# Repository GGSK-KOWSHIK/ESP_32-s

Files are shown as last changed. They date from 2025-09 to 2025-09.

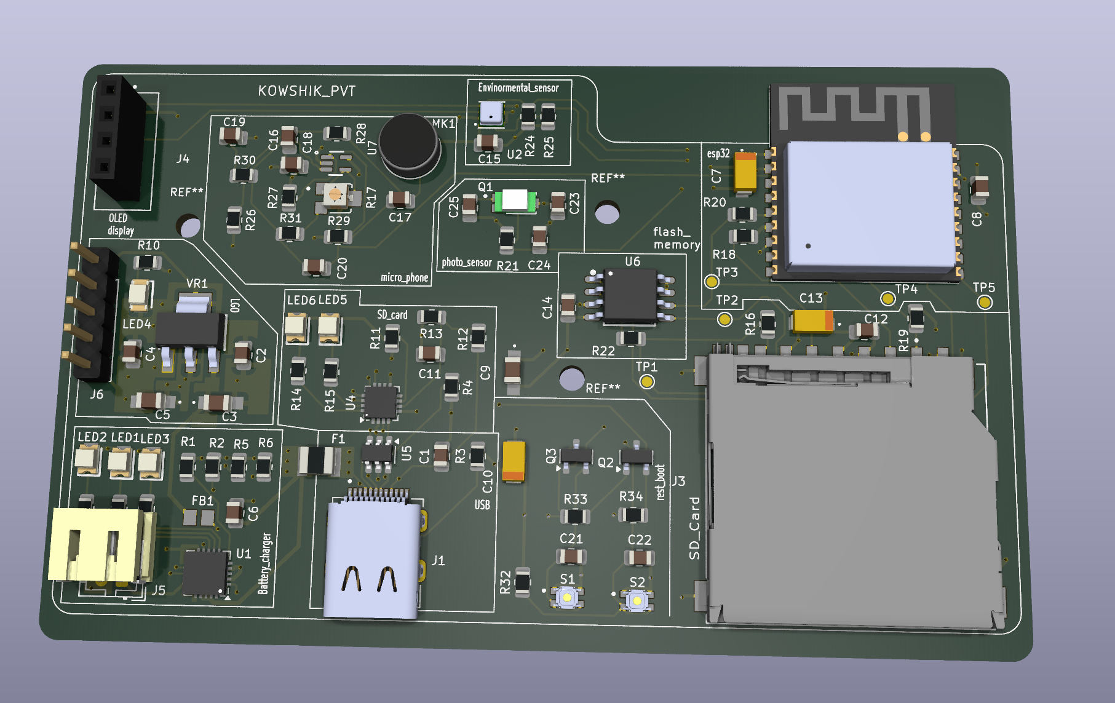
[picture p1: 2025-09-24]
Images/PCB_3D.png

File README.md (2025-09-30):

## Project Summary:4 Layers Custom IoT PCB with ESP32-C3-02.

This project involves the design and development of a **4-layer custom PCB** for an IoT application powered by the ESP32-C3-02 SoC. The board integrates **Wi-Fi/BLE connectivity** and **TP4056-based Li-ion charging circuitry**, enabling efficient and safe charging of a single-cell Li-ion battery.

### Key Features

- **Microcontroller**: ESP32-C3-02 SoC with Wi-Fi and BLE connectivity  
- **Power Management**: TP4056 IC for single-cell Li-ion battery charging with thermal regulation  
- **Battery Protection**: Integrated under-voltage lockout and trickle charging  
- **Sensors and Modules**:  
  - BME280 for temperature, humidity, and pressure sensing  
  - Ambient light and sound sensors  
  - Mini SD card reader for local data storage  
  - Onboard flash memory for extended storage  
- **Display**: I2C OLED for real-time data visualization  
- **Power Inputs**:  
  - USB-C connector for charging and data transfer  
  - LiPo battery connector with onboard charging circuitry  
- **Indicators**: LED indicators showing charging and full-charge status  

### Design Highlights

1. **Power Supply Integration**  
   - USB-C powers both charging and system operation  
   - TP4056 manages charging and protection  
   - Regulated supply ensures ESP32-C3-02 stability  

2. **Modular Architecture**  
   - Supports multiple onboard sensors  
   - Expandable via additional I2C devices  

3. **Safe and Efficient Charging**  
   - Programmable charging current (external resistor)  
   - Automatic charge termination and built-in protection  

4. **Compact and Reliable Layout**  
   - Optimized **4-layer PCB routing** for minimal power loss  
   - Thermal management for TP4056 and critical components  

### Applications

- IoT edge devices for environmental monitoring  
- Low-power battery-operated data logging systems  
- Prototyping platform for ESP32-based IoT solutions

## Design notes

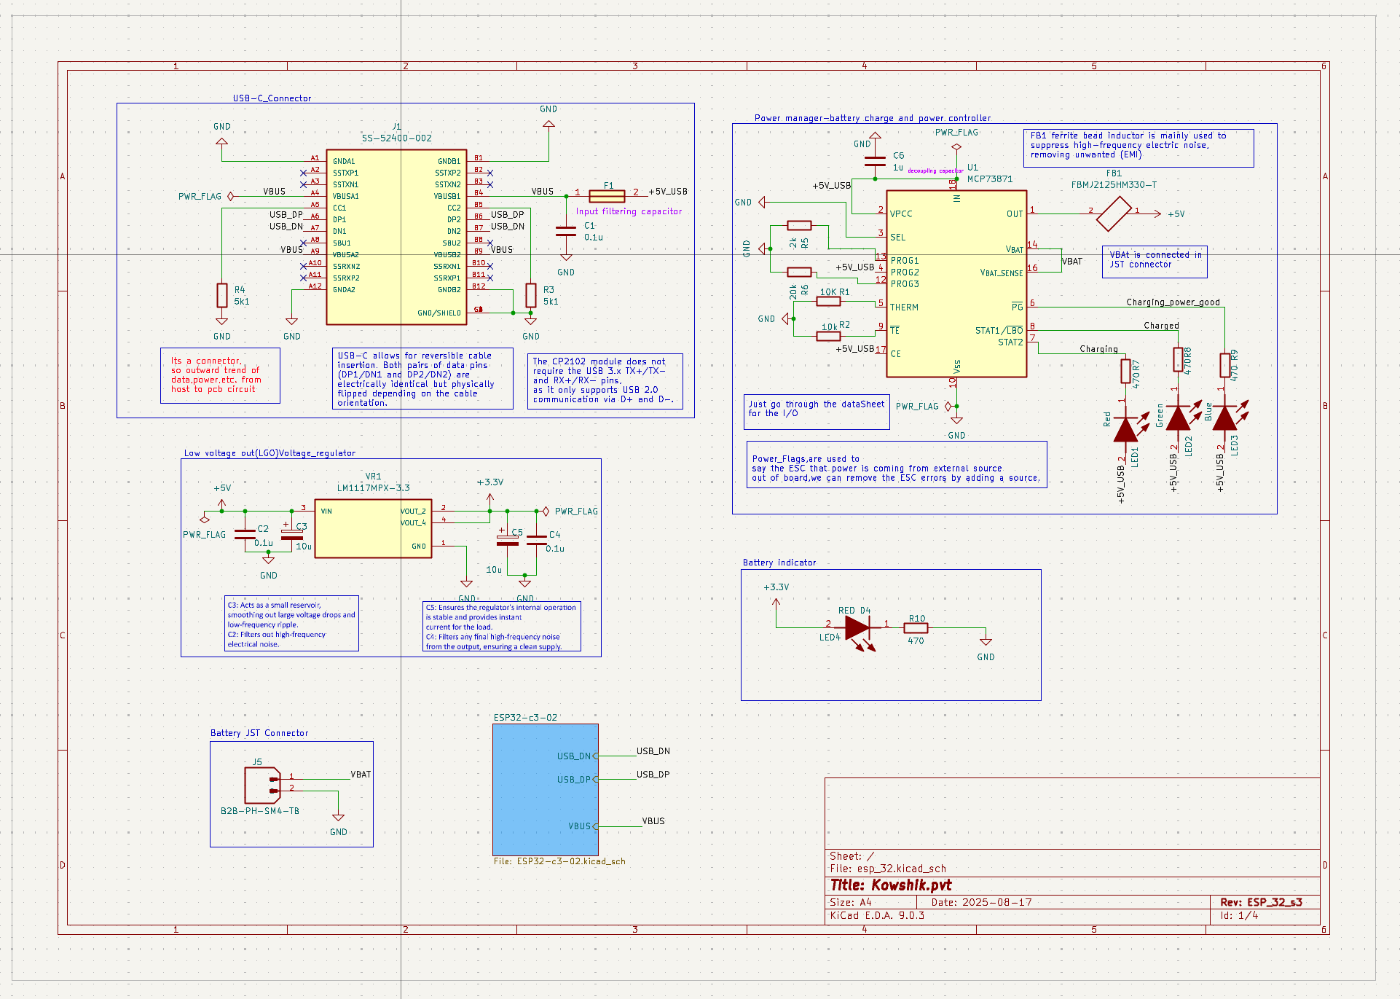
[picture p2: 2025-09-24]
Images/Schematic_1.png

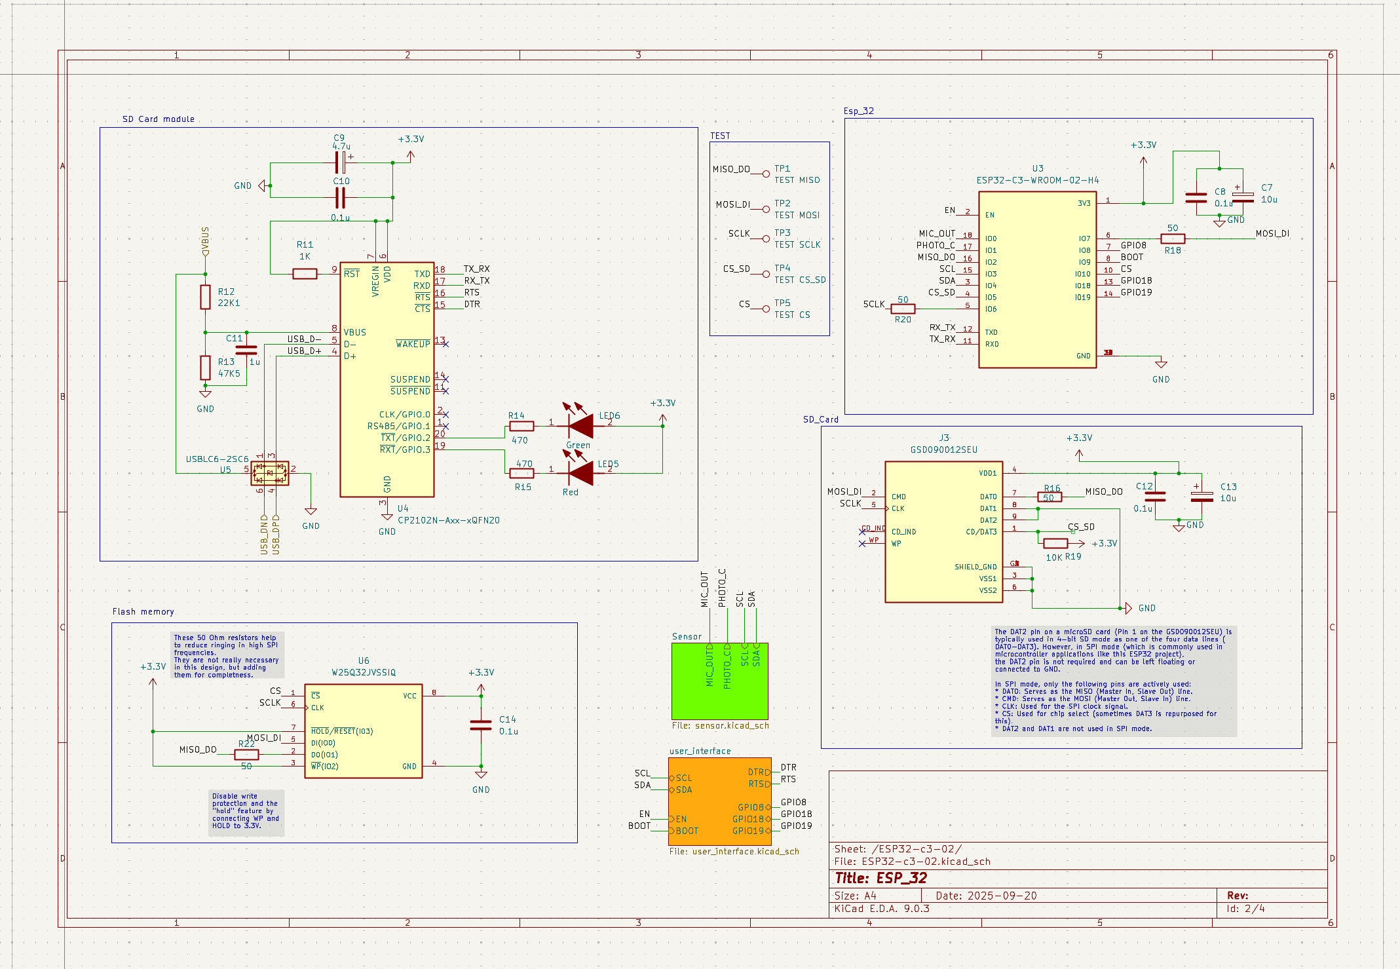
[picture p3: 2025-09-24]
Images/schematic_2.png

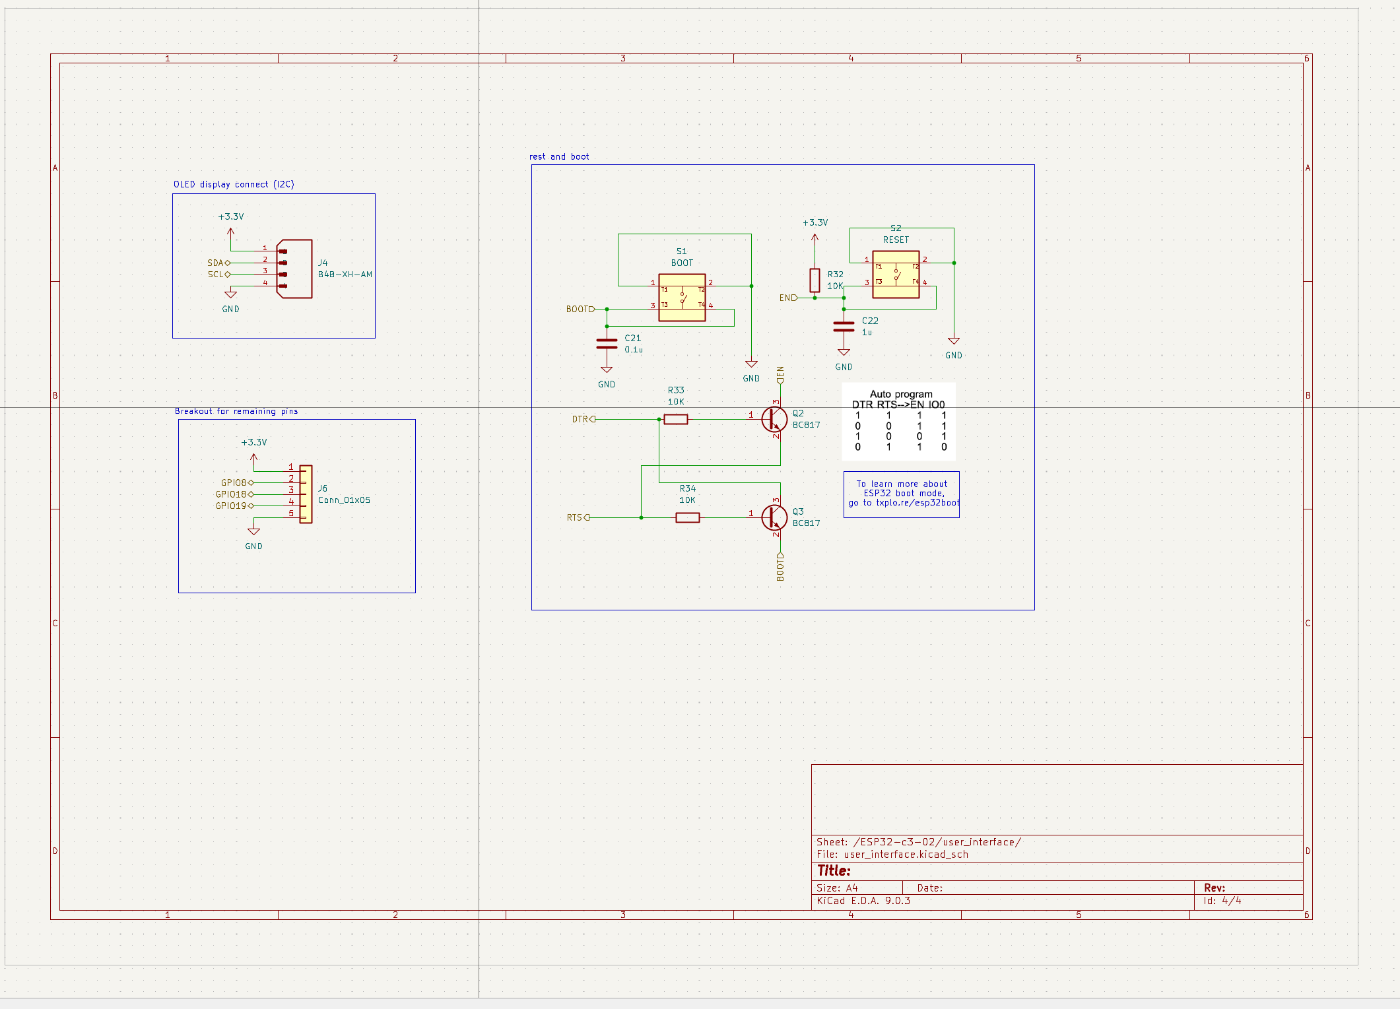
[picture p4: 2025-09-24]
Images/schematic_3.png

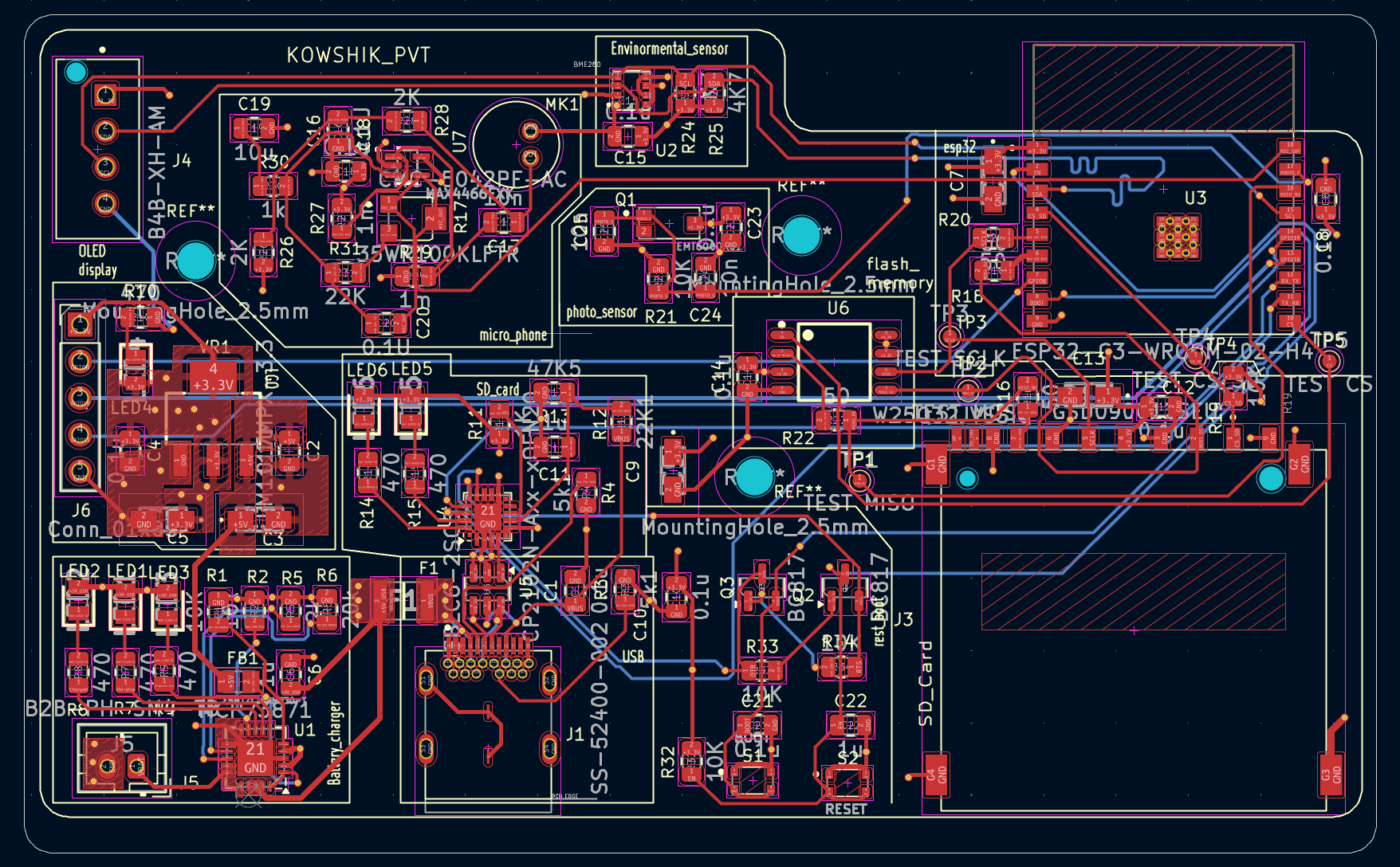
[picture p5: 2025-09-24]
Images/PCB.png

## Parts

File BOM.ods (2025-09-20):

DESIGNATOR | QTY | VALUE | MANUF. PART No | MANUFACTURER | PACKAGE | DESCRIPTION
C1, C2, C5, C8, C10, C13-C16, C18, C21, C23 | 12 | 0.1u | C0805C104K4RAC | KEMET | 0805 | Multilayer Ceramic Capacitors MLCC - SMD/SMT 16V 0.1uF X7R 0805 10%
C3, C4, C7, C12 | 4 | 10u | T491A106K010AT7280 | KEMET | 1206 | T491, Tantalum, MnO2 Tantalum, Commercial Grade, 10 uF, 10%, 10 VDC, 125C, -55C, 85C, SMD, MnO2, Molded, 6 % , 3.8 Ohms, 1000 nA, 58.6 mg, 3216, 1.6mm, Height Max = 1.8mm, 9000, 156 Weeks
C6, C11, C22 | 3 | 1u | C0805C105K4RACTU | KEMET | 0805 | Multilayer Ceramic Capacitors MLCC - SMD/SMT 16V 1uF X7R 0805 10%
C9 | 1 | 4.7u | T491A475K010AT7280 | KEMET | 1206 | T491, Tantalum, MnO2 Tantalum, Commercial Grade, 4.7 uF, 10%, 10 VDC, 125C, -55C, 85C, SMD, MnO2, Molded, 6 % , 4 Ohms, 500 nA, 58.6 mg, 3216, 1.6mm, Height Max = 1.8mm, 9000, 156 Weeks
C17, C24, C25 | 3 | 10n | C0603C103K4RACTU | KEMET | 0603 | Multilayer Ceramic Capacitors MLCC - SMD/SMT 16V 0.01uF X7R 0603 10%
C19 | 1 | 10uF | C1206C106K4RAC | KEMET | 1206 | Multilayer Ceramic Capacitors MLCC - SMD/SMT 16V 10uF X7R 1206 10%
C20 | 1 | 100pF | C0603C101K4RACTU | KEMET | 0603 | Multilayer Ceramic Capacitors MLCC - SMD/SMT 16V 100pF X7R 0603 10%
D1, D4, D6 | 3 | RED | LTST-C170KRKT | Lite-On | 0805 | Standard LEDs - SMD Red Clear 631nm
D2, D5 | 2 | GREEN | LTST-C170GKT | Lite-On | 0805 | LED,SMD,0805,Green,6mcd,130deg Lite-On LTST-C170GKT, CHIPLED 0805 Series Green LED, 569 nm 2012 (0805), Rectangle Lens SMD package
D3 | 1 | BLUE | LTST-C170TBKT | Lite-On | 0805 | LED,SMD,0805,Blue,28mcd,130deg
F1 | 1 | 0ZCH0110AF2E | 0ZCH0110AF2E | Belfuse | 1210 | 1210 SMT PPTC | 1.10 Ih | 16V
J1 | 1 | USB_C_Receptacle | SS-52400-002 | STEWART CONNECTOR | USB Type-C | USB 2.0-only Type-C Receptacle connector
J2 | 1 | JST_2mm_LiPo | PHR-2 | JST |  | 2 Pin 2mm JST Battery Connector
J3 | 1 | GSD090012SEU | GSD090012SEU | Amphenol |  | Memory Card Connectors SD CARD CONNECTOR 9 POS, SMT
J4, J5 | 2 | B4B-XH-AM | B4B-XH-AM | JST |  | Connector header vertical 4pos 2.5mm
J6 | 1 | Conn_01x05 |  |  |  | Header 1X5, 2.54mm
L1 | 1 |  | FBMJ2125HM330 | TAIYO YUDEN | 0805 | Ferrite Bead 0805 4A 33OHMS 25%
MK1 | 1 | CMC-5042PF-AC | CMC-5042PF-AC | CUI INC
Q1 | 1 | TEMT6000X01 | TEMT6000X01 | VISHAY | 4 mm x 2 mm x 1.05 mm | Ambient Light Sensors Ambient Light Sensor AEC-Q101 Qualified
Q2, Q3 | 2 | BC817 | BC817 |  | SOT-23 | 0.8A Ic, 45V Vce, NPN Transistor, SOT-23
R1, R2, R19, R23, R32-R34 | 7 | 10K |  |  | 805 | SMD resistor, 0805, 125mW, 1%
R3, R4 | 2 | 5k1 |  |  | 0805 | SMD resistor, 0805, 125mW, 1%
R5, R26, R28 | 3 | 2K |  |  | 0805 | SMD resistor, 0805, 125mW, 1%
R6 | 1 | 20K |  |  | 0805 | SMD resistor, 0805, 125mW, 1%
R7-R9 | 3 | 470 |  |  | 0805 | SMD resistor, 0805, 125mW, 1%
R10, R14, R18 | 3 | 330 |  |  | 0805 | SMD resistor, 0805, 125mW, 1%
R11, R30 | 2 | 1K |  |  | 0805 | SMD resistor, 0805, 125mW, 1%
R12 | 1 | 22K1 |  |  | 0805 | SMD resistor, 0805, 125mW, 1%
R13 | 1 | 47K5 |  |  | 0805 | SMD resistor, 0805, 125mW, 1%
R15-R17, R20-R22 | 6 | 50 |  |  | 0805 | SMD resistor, 0805, 125mW, 1%
R24, R25 | 2 | 4K7 |  |  | 0805 | SMD resistor, 0805, 125mW, 1%
R27, R29 | 2 | 1M |  |  | 0805 | SMD resistor, 0805, 125mW, 1%
R31 | 1 | 22K |  |  | 0805 | SMD resistor, 0805, 125mW, 1%
SW1, SW2 | 2 | TL3305AF260QG | TL3305AF260QG | E-Switch |  | Tactile Switches 50mA 12VDC SPST, NO 3.8mm Act 260gf
U1 | 1 | MCP73871 | MCP73871-4CCI/ML | Microchip | QFN-20 | Single cell, Li-Ion/Li-Po charge management controller
U2 | 1 | LM1117MPX-3.3_NOPB | LM1117MPX-3.3/NOPB | Texas Instruments | SOT-223-4 | Space saving 800-mA low-dropout linear regulator with internal current limit
U3 | 1 | ESP32-C3-WROOM-02-H4 | ESP32-C3-WROOM-02-H4 | Espressif |  | Multiprotocol Modules SMD module, ESP32-C3, 4MB SPI flash, PCB antenna
U4 | 1 | CP2102N-A02-GQFN20 | CP2102N-A02-GQFN20 | Silicon Laboratories | QFN20 | USB to UART Bridge
U5 | 1 | USBLC6-2SC6 | USBLC6-2SC6 | STMicroelectronics | SOT-23-6 | ESD Suppressors / TVS Diodes ESD Protection Low Cap
U6 | 1 | W25Q32JVSSIQ | W25Q32JVSSIQ | Winbond | SOIC-8 | NOR Flash spiFlash, 32M-bit, 4Kb Uniform Sector
U7 | 1 | BME280 | BME280 | Bosch | LGA-8 | Air Quality Sensor MEMS humidity, pressure and temperature sensor
U8 | 1 | MAX4466EXK+T | MAX4466EXK+T | Analog Devices Inc. | SC-70-5 | Microphone Preamplifier
VR1 | 1 | 35WR100KLFTR | 35WR100KLFTR | TT Electronics |  | Trimmer Resistor - SMD 3mm 100K Open Type

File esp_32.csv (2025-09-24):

Reference | Qty | Value | DNP | Exclude from BOM | Exclude from Board | Footprint | Datasheet
C1,C2,C4,C8,C10,C12,C14,C15,C18,C21,C23 | 11 | 0.1u |  |  |  | Capacitor_SMD:C_0805_2012Metric | ~
C3,C5,C7,C13 | 4 | 10u |  |  |  | Footprints:T491A | ~
C6,C11,C22 | 3 | 1u |  |  |  | Capacitor_SMD:C_0805_2012Metric | ~
C9 | 1 | 4.7u |  |  |  | Footprints:T491A | ~
C16,C20 | 2 | 0.1U |  |  |  | Capacitor_SMD:C_0805_2012Metric | ~
C17,C24,C25 | 3 | 10n |  |  |  | Capacitor_SMD:C_0805_2012Metric | ~
C19 | 1 | 10u |  |  |  | Capacitor_SMD:C_0805_2012Metric | ~
F1 | 1 | 0ZCH0110AF2E |  |  |  | Footprints:FUSC3226X100N | https://www.belfuse.com/resources/datasheets/circuitprotection/ds-cp-0zch-series.pdf
FB1 | 1 | FBMJ2125HM330-T |  |  |  | Footprints:BEADC2012X105N
J1 | 1 | SS-52400-002 |  |  |  | Footprints:BELFUSE_SS-52400-002
J3 | 1 | GSD090012SEU |  |  |  | Footprints:AMPHENOL_GSD090012SEU
J4 | 1 | B4B-XH-AM |  |  |  | Footprints:JST_B4B-XH-AM__LF__SN_
J5 | 1 | B2B-PH-SM4-TB |  |  |  | Connector_JST:JST_PH_B2B-PH-K_1x02_P2.00mm_Vertical
J6 | 1 | Conn_01x05 |  |  |  | Connector_PinHeader_2.54mm:PinHeader_1x05_P2.54mm_Vertical | ~
LED1,LED5 | 2 | Red |  |  |  | Footprints:LEDC2012X120N | https://componentsearchengine.com/Datasheets/1/LTST-C170KRKT.pdf
LED2,LED6 | 2 | Green |  |  |  | Footprints:LEDC2012X120N | https://mm.digikey.com/Volume0/opasdata/d220001/medias/docus/895/LTST-C170GKT.pdf
LED3 | 1 | Blue |  |  |  | Footprints:LEDC2012X120N | https://componentsearchengine.com/Datasheets/1/LTST-C170TBKT.pdf
LED4 | 1 | RED D4 |  |  |  | Footprints:LEDC2012X120N | https://componentsearchengine.com/Datasheets/1/LTST-C170KRKT.pdf
MK1 | 1 | CMC-5042PF-AC |  |  |  | Footprints:CUI_CMC-5042PF-AC
Q1 | 1 | TEMT6000X01 |  |  |  | Footprints:TRANS_TEMT6000X01
Q2,Q3 | 2 | BC817 |  |  |  | Package_TO_SOT_SMD:SOT-23 | https://www.onsemi.com/pub/Collateral/BC818-D.pdf
R1,R19,R21,R32,R33,R34 | 6 | 10K |  |  |  | Resistor_SMD:R_0805_2012Metric | ~
R2 | 1 | 10k |  |  |  | Resistor_SMD:R_0805_2012Metric | ~
R3,R4 | 2 | 5k1 |  |  |  | Resistor_SMD:R_0805_2012Metric | ~
R5 | 1 | 2k |  |  |  | Resistor_SMD:R_0805_2012Metric | ~
R6 | 1 | 20k |  |  |  | Resistor_SMD:R_0805_2012Metric | ~
R7,R8,R9,R10,R14,R15 | 6 | 470 |  |  |  | Resistor_SMD:R_0805_2012Metric | ~
R11 | 1 | 1K |  |  |  | Resistor_SMD:R_0805_2012Metric | ~
R12 | 1 | 22K1 |  |  |  | Resistor_SMD:R_0805_2012Metric | ~
R13 | 1 | 47K5 |  |  |  | Resistor_SMD:R_0805_2012Metric | ~
R16,R18,R20,R22 | 4 | 50 |  |  |  | Resistor_SMD:R_0805_2012Metric | ~
R17 | 1 | 35WR100KLFTR |  |  |  | Footprints:TRIM_35WR100KLFTR
R24,R25 | 2 | 4K7 |  |  |  | Resistor_SMD:R_0805_2012Metric | ~
R26,R28 | 2 | 2K |  |  |  | Resistor_SMD:R_0805_2012Metric | ~
R27,R29 | 2 | 1m |  |  |  | Resistor_SMD:R_0805_2012Metric | ~
R30 | 1 | 1k |  |  |  | Resistor_SMD:R_0805_2012Metric | ~
R31 | 1 | 22K |  |  |  | Resistor_SMD:R_0805_2012Metric | ~
S1 | 1 | BOOT |  |  |  | Footprints:SW_USLPT2819DT2TR
S2 | 1 | RESET |  |  |  | Footprints:SW_USLPT2819DT2TR
TP1 | 1 | TEST MISO |  |  |  | TestPoint:TestPoint_Pad_D1.0mm | ~
TP2 | 1 | TEST MOSI |  |  |  | TestPoint:TestPoint_Pad_D1.0mm | ~
TP3 | 1 | TEST SCLK |  |  |  | TestPoint:TestPoint_Pad_D1.0mm | ~
TP4 | 1 | TEST CS_SD |  |  |  | TestPoint:TestPoint_Pad_D1.0mm | ~
TP5 | 1 | TEST CS |  |  |  | TestPoint:TestPoint_Pad_D1.0mm | ~
U1 | 1 | MCP73871 |  |  |  | Package_DFN_QFN:QFN-20-1EP_4x4mm_P0.5mm_EP2.5x2.5mm | http://www.mouser.com/ds/2/268/22090a-52174.pdf
U2 | 1 | BME280 |  |  |  | Footprints:PSON65P250X250X100-8N
U3 | 1 | ESP32-C3-WROOM-02-H4 |  |  |  | Footprints:MODULE_ESP32-C3-WROOM-02-H4
U4 | 1 | CP2102N-Axx-xQFN20 |  |  |  | Package_DFN_QFN:SiliconLabs_QFN-20-1EP_3x3mm_P0.5mm_EP1.8x1.8mm | https://www.silabs.com/documents/public/data-sheets/cp2102n-datasheet.pdf
U5 | 1 | USBLC6-2SC6 |  |  |  | Package_TO_SOT_SMD:SOT-23-6 | https://www.st.com/resource/en/datasheet/usblc6-2.pdf
U6 | 1 | W25Q32JVSSIQ |  |  |  | Footprints:SOIC127P790X216-8N
U7 | 1 | MAX4466EXK |  |  |  | Footprints:SOT65P210X110-5N
VR1 | 1 | LM1117MPX-3.3 |  |  |  | Footprints:VREG_LM1117MPX-3.3

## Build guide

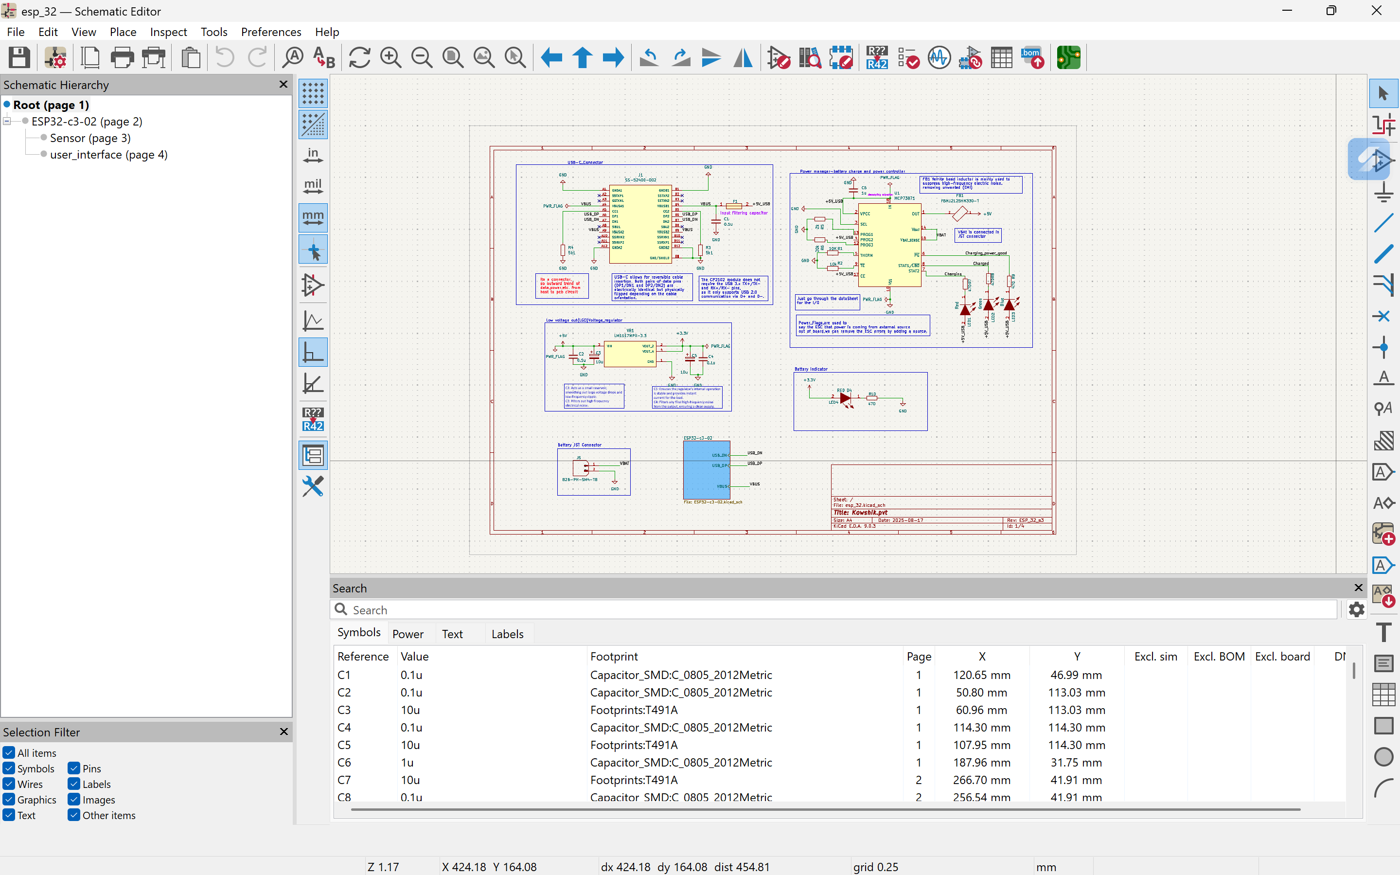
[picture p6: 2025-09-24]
Images/complete_setup.png

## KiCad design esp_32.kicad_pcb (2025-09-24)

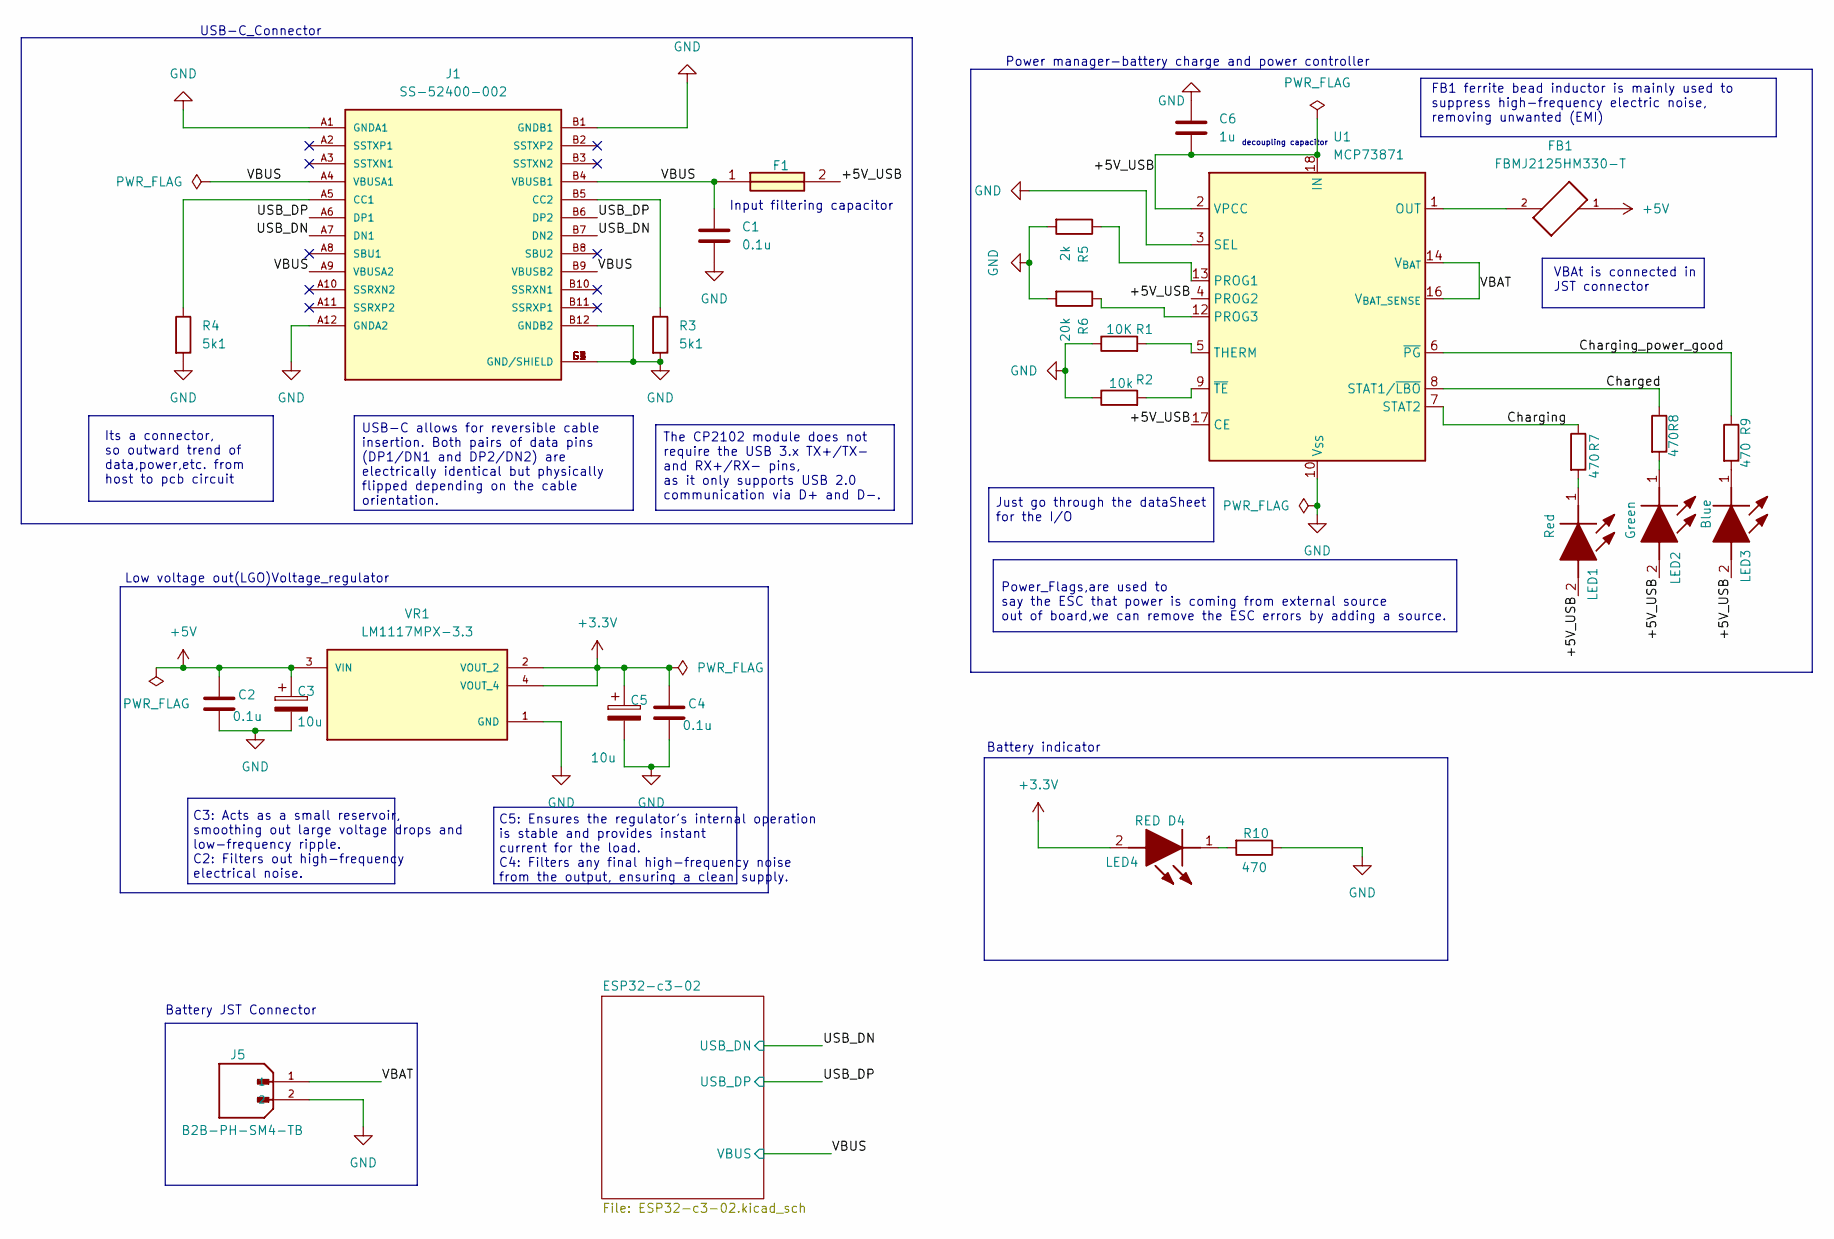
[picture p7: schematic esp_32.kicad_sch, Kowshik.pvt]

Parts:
C1, C2, C4: 0.1u; C_0805_2012Metric
C3, C5: 10u; T491A
C6: 1u; C_0805_2012Metric
F1: 0ZCH0110AF2E; FUSC3226X100N; Manufacturer_Part_Number 0ZCH0110AF2E
FB1: FBMJ2125HM330-T; BEADC2012X105N
J1: SS-52400-002; BELFUSE_SS-52400-002; PARTREV A0
J5: B2B-PH-SM4-TB; JST_PH_B2B-PH-K_1x02_P2.00mm_Vertical; PARTREV N/A
LED1: Red; LEDC2012X120N; Manufacturer_Part_Number LTST-C170KRKT; Mouser Part Number 859-LTST-C170KRKT
LED2: Green; LEDC2012X120N; Manufacturer_Part_Number LTST-C170GKT; Mouser Part Number 859-LTST-C170GKT
LED3: Blue; LEDC2012X120N; Manufacturer_Part_Number LTST-C170TBKT; Mouser Part Number 859-LTST-C170TBKT
LED4: RED D4; LEDC2012X120N; Manufacturer_Part_Number LTST-C170KRKT; Mouser Part Number 859-LTST-C170KRKT
R1: 10K; R_0805_2012Metric
R2: 10k; R_0805_2012Metric
R3, R4: 5k1; R_0805_2012Metric
R5: 2k; R_0805_2012Metric
R6: 20k; R_0805_2012Metric
R7, R8, R9, R10: 470; R_0805_2012Metric
U1: MCP73871; QFN-20-1EP_4x4mm_P0.5mm_EP2.5x2.5mm
VR1: LM1117MPX-3.3; VREG_LM1117MPX-3.3

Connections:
+3.3V: C4.1, C5.1, LED4.2 (A), VR1.2 (VOUT_2), VR1.4 (VOUT_4); also elsewhere on the board
+5V: C2.1, C3.1, FB1.1, VR1.3 (VIN)
/+5V_USB: C6.2, F1.2, LED1.2 (A), LED2.2 (A), LED3.2 (A), U1.2 (VPCC), U1.4 (PROG2), U1.17 (CE), U1.18 (IN), U1.19 (IN)
/Charged: R8.1, U1.8 (STAT1/~LBO)
/Charging: R7.1, U1.7 (STAT2)
/Charging_power_good: R9.1, U1.6 (~PG)
/USB_DN: J1.A7 (DN1), J1.B7 (DN2); also elsewhere on the board
/USB_DP: J1.A6 (DP1), J1.B6 (DP2); also elsewhere on the board
/VBAT: J5.1, U1.14 (V_{BAT}), U1.15 (V_{BAT}), U1.16 (V_{BAT_SENSE})
/VBUS: C1.1, F1.1, J1.A4 (VBUSA1), J1.A9 (VBUSA2), J1.B4 (VBUSB1), J1.B9 (VBUSB2); also elsewhere on the board
GND: C1.2, C2.2, C3.2, C4.2, C5.2, C6.1, J1.A1 (GNDA1), J1.A12 (GNDA2), J1.B1 (GNDB1), J1.B12 (GNDB2), J1.G1 (GND/SHIELD), J1.G2 (GND/SHIELD), J1.G3 (GND/SHIELD), J1.G4 (GND/SHIELD), J1.S1 (GND/SHIELD), J1.S2 (GND/SHIELD), J1.S3 (GND/SHIELD), J1.S4 (GND/SHIELD), J5.2, R1.1, R2.1, R3.2, R4.2, R5.2, R6.2, R10.1, U1.3 (SEL), U1.10 (V_{SS}), U1.11 (V_{SS}), U1.21 (V_{SS}), VR1.1 (GND); also elsewhere on the board
unnamed: FB1.2, U1.1 (OUT), U1.20 (OUT)
unnamed: J1.A5 (CC1), R4.1
unnamed: J1.B5 (CC2), R3.1
unnamed: LED1.1 (K), R7.2
unnamed: LED2.1 (K), R8.2
unnamed: LED3.1 (K), R9.2
unnamed: LED4.1 (K), R10.2
unnamed: R5.1, U1.13 (PROG1)
unnamed: R6.1, U1.12 (PROG3)
unnamed: R1.2, U1.5 (THERM)
unnamed: R2.2, U1.9 (~TE)

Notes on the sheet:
Input filtering capacitor
Power manager-battery charge and power controller
C3: Acts as a small reservoir, smoothing out large voltage drops and low-frequency ripple. C2: Filters out high-frequency electrical noise.
Battery indicator
Low voltage out(LGO)Voltage_regulator
Battery JST Connector
Power_Flags,are used to say the ESC that power is coming from external source out of board,we can remove the ESC errors by adding a source.
VBAt is connected in JST connector
Its a connector, so outward trend of data,power,etc. from host to pcb circuit
C5: Ensures the regulator's internal operation is stable and provides instant current for the load. C4: Filters any final high-frequency noise from the output, ensuring a clean supply.
decoupling capacitor
USB-C_Connector
Just go through the dataSheet for the I/O
FB1 ferrite bead inductor is mainly used to suppress high-frequency electric noise, removing unwanted (EMI)
USB-C allows for reversible cable insertion. Both pairs of data pins (DP1/DN1 and DP2/DN2) are electrically identical but physically flipped depending on the cable orientation.
The CP2102 module does not require the USB 3.x TX+/TX- and RX+/RX- pins, as it only supports USB 2.0 communication via D+ and D-.

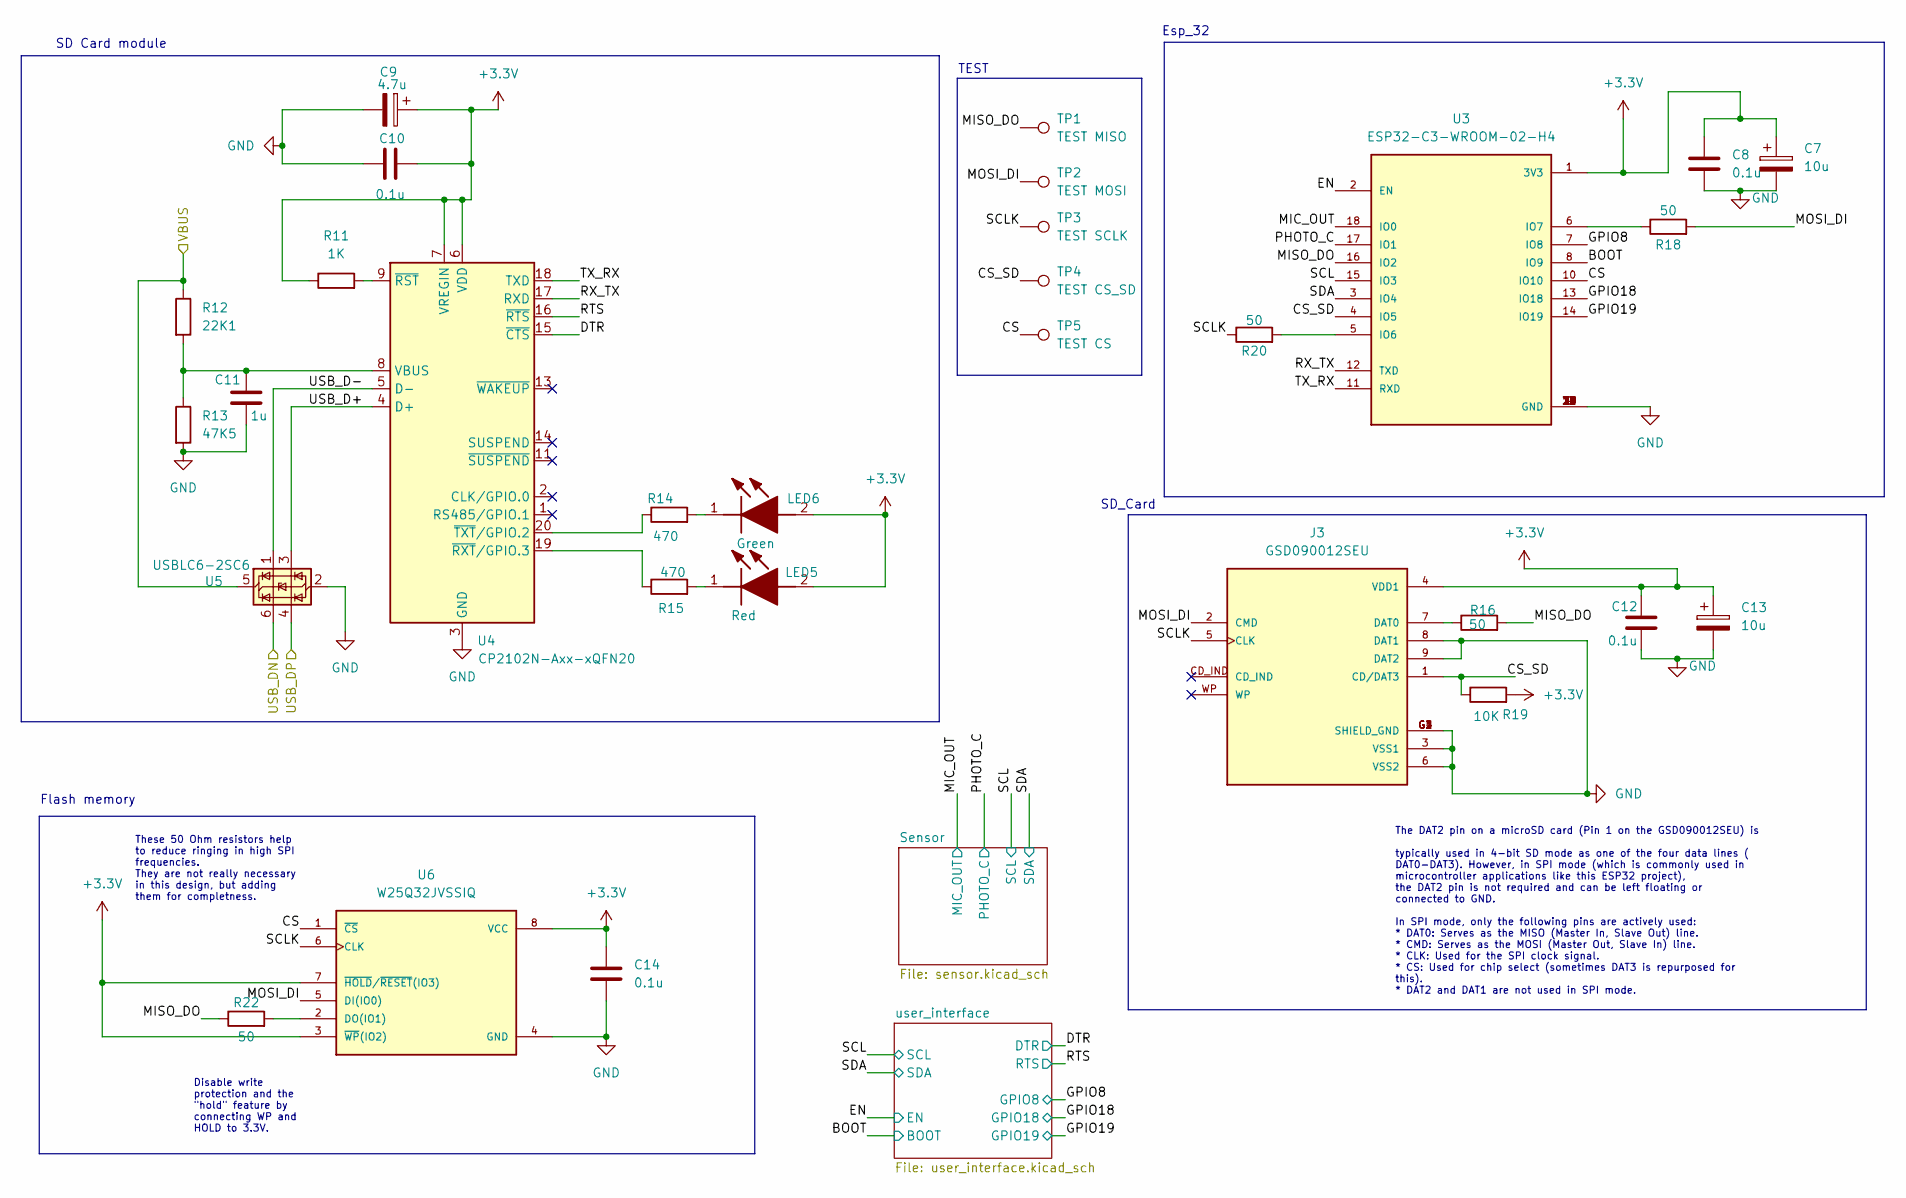
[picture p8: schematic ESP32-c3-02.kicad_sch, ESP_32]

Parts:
C7, C13: 10u; T491A
C8, C10, C12, C14: 0.1u; C_0805_2012Metric
C9: 4.7u; T491A
C11: 1u; C_0805_2012Metric
J3: GSD090012SEU; AMPHENOL_GSD090012SEU; PARTREV E
LED5: Red; LEDC2012X120N; Manufacturer_Part_Number LTST-C170KRKT; Mouser Part Number 859-LTST-C170KRKT
LED6: Green; LEDC2012X120N; Manufacturer_Part_Number LTST-C170GKT; Mouser Part Number 859-LTST-C170GKT
R11: 1K; R_0805_2012Metric
R12: 22K1; R_0805_2012Metric
R13: 47K5; R_0805_2012Metric
R14, R15: 470; R_0805_2012Metric
R16, R18, R20, R22: 50; R_0805_2012Metric
R19: 10K; R_0805_2012Metric
TP1: TEST MISO; TestPoint_Pad_D1.0mm
TP2: TEST MOSI; TestPoint_Pad_D1.0mm
TP3: TEST SCLK; TestPoint_Pad_D1.0mm
TP4: TEST CS_SD; TestPoint_Pad_D1.0mm
TP5: TEST CS; TestPoint_Pad_D1.0mm
U3: ESP32-C3-WROOM-02-H4; MODULE_ESP32-C3-WROOM-02-H4
U4: CP2102N-Axx-xQFN20; SiliconLabs_QFN-20-1EP_3x3mm_P0.5mm_EP1.8x1.8mm
U5: USBLC6-2SC6; SOT-23-6
U6: W25Q32JVSSIQ; SOIC127P790X216-8N; M_PART_NUMBER W25QXX

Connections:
+3.3V: C7.1, C8.1, C9.1, C10.2, C12.1, C13.1, C14.1, J3.4 (VDD1), LED5.2 (A), LED6.2 (A), R11.1, R19.2, U3.1 (3V3), U4.6 (VDD), U4.7 (VREGIN), U6.3 (~WP(IO2)), U6.7 (~HOLD/~RESET(IO3)), U6.8 (VCC); also elsewhere on the board
/ESP32-c3-02/BOOT: U3.8 (IO9); also elsewhere on the board
/ESP32-c3-02/CS: TP5.1, U3.10 (IO10), U6.1 (~CS)
/ESP32-c3-02/CS_SD: J3.1 (CD/DAT3), R19.1, TP4.1, U3.4 (IO5)
/ESP32-c3-02/DTR: U4.15 (~CTS); also elsewhere on the board
/ESP32-c3-02/EN: U3.2 (EN); also elsewhere on the board
/ESP32-c3-02/GPIO8: U3.7 (IO8); also elsewhere on the board
/ESP32-c3-02/GPIO18: U3.13 (IO18); also elsewhere on the board
/ESP32-c3-02/GPIO19: U3.14 (IO19); also elsewhere on the board
/ESP32-c3-02/MIC_OUT: U3.18 (IO0); also elsewhere on the board
/ESP32-c3-02/MISO_DO: R16.2, R22.1, TP1.1, U3.16 (IO2)
/ESP32-c3-02/MOSI_DI: J3.2 (CMD), R18.2, TP2.1, U6.5 (DI(IO0))
/ESP32-c3-02/PHOTO_C: U3.17 (IO1); also elsewhere on the board
/ESP32-c3-02/RTS: U4.16 (~RTS); also elsewhere on the board
/ESP32-c3-02/RX_TX: U3.12 (TXD), U4.17 (RXD)
/ESP32-c3-02/SCL: U3.15 (IO3); also elsewhere on the board
/ESP32-c3-02/SCLK: J3.5 (CLK), R20.1, TP3.1, U6.6 (CLK)
/ESP32-c3-02/SDA: U3.3 (IO4); also elsewhere on the board
/ESP32-c3-02/TX_RX: U3.11 (RXD), U4.18 (TXD)
/ESP32-c3-02/USB_D+: U4.4 (D+), U5.3 (I/O2)
/ESP32-c3-02/USB_D-: U4.5 (D-), U5.1 (I/O1)
/USB_DN: U5.6 (I/O1); also elsewhere on the board
/USB_DP: U5.4 (I/O2); also elsewhere on the board
/VBUS: R12.1, U5.5 (VBUS); also elsewhere on the board
GND: C7.2, C8.2, C9.2, C10.1, C11.2, C12.2, C13.2, C14.2, J3.3 (VSS1), J3.6 (VSS2), J3.8 (DAT1), J3.9 (DAT2), J3.G1 (SHIELD_GND), J3.G2 (SHIELD_GND), J3.G3 (SHIELD_GND), J3.G4 (SHIELD_GND), R13.2, U3.9 (GND), U3.19 (GND), U3.20 (GND), U3.21 (GND), U3.22 (GND), U3.23 (GND), U3.24 (GND), U3.25 (GND), U3.26 (GND), U3.27 (GND), U3.28 (GND), U3.29 (GND), U3.30 (GND), U3.31 (GND), U3.32 (GND), U3.33 (GND), U3.34 (GND), U3.35 (GND), U3.36 (GND), U3.37 (GND), U3.38 (GND), U3.39 (GND), U4.3 (GND), U4.12 (GND), U4.21 (GND), U5.2 (GND), U6.4 (GND); also elsewhere on the board
unnamed: J3.7 (DAT0), R16.1
unnamed: LED5.1 (K), R15.2
unnamed: LED6.1 (K), R14.2
unnamed: R20.2, U3.5 (IO6)
unnamed: R18.1, U3.6 (IO7)
unnamed: C11.1, R12.2, R13.1, U4.8 (VBUS)
unnamed: R11.2, U4.9 (~RST)
unnamed: R15.1, U4.19 (~RXT/GPIO.3)
unnamed: R14.1, U4.20 (~TXT/GPIO.2)
unnamed: R22.2, U6.2 (DO(IO1))

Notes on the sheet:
SD Card module
SD_Card
Esp_32
TEST
Flash memory
These 50 Ohm resistors help to reduce ringing in high SPI frequencies. They are not really necessary in this design, but adding them for completness.
The DAT2 pin on a microSD card (Pin 1 on the GSD090012SEU) is typically used in 4-bit SD mode as one of the four data lines ( DAT0-DAT3). However, in SPI mode (which is commonly used in microcontroller applications like this ESP32 project), the DAT2 pin is not required and can be left floating or c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
Disable write protection and the "hold" feature by connecting WP and HOLD to 3.3V.

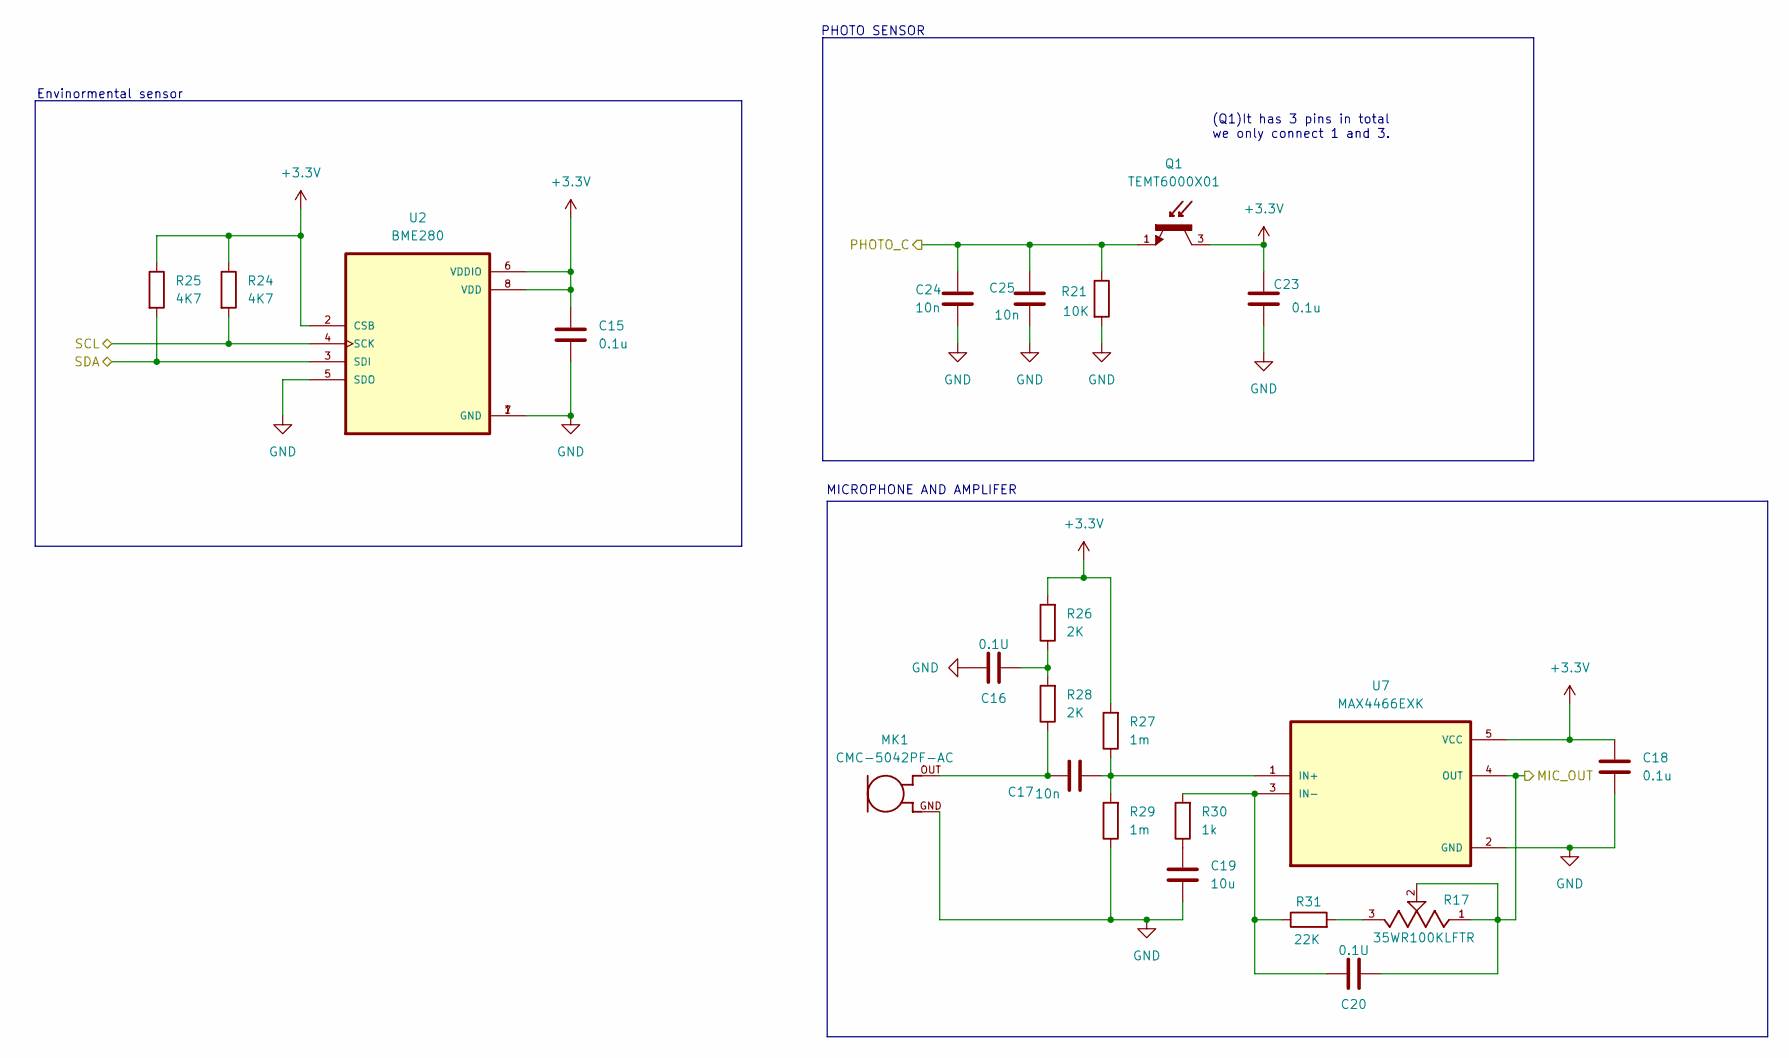
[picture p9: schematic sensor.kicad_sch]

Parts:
C15, C18, C23: 0.1u; C_0805_2012Metric
C16, C20: 0.1U; C_0805_2012Metric
C17, C24, C25: 10n; C_0805_2012Metric
C19: 10u; C_0805_2012Metric
MK1: CMC-5042PF-AC; CUI_CMC-5042PF-AC
Q1: TEMT6000X01; TRANS_TEMT6000X01; PARTREV 1.9
R17: 35WR100KLFTR; TRIM_35WR100KLFTR; PARTREV D
R21: 10K; R_0805_2012Metric
R24, R25: 4K7; R_0805_2012Metric
R26, R28: 2K; R_0805_2012Metric
R27, R29: 1m; R_0805_2012Metric
R30: 1k; R_0805_2012Metric
R31: 22K; R_0805_2012Metric
U2: BME280; PSON65P250X250X100-8N
U7: MAX4466EXK; SOT65P210X110-5N

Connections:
+3.3V: C15.1, C18.1, C23.1, Q1.3, R24.1, R25.1, R26.2, R27.2, U2.2 (CSB), U2.6 (VDDIO), U2.8 (VDD), U7.5 (VCC); also elsewhere on the board
/ESP32-c3-02/MIC_OUT: C20.2, R17.1, R17.2, U7.4 (OUT); also elsewhere on the board
/ESP32-c3-02/PHOTO_C: C24.1, C25.1, Q1.1, R21.1; also elsewhere on the board
/ESP32-c3-02/SCL: R24.2, U2.4 (SCK); also elsewhere on the board
/ESP32-c3-02/SDA: R25.2, U2.3 (SDI); also elsewhere on the board
GND: C15.2, C16.1, C18.2, C19.2, C23.2, C24.2, C25.2, MK1.GND, R21.2, R29.1, U2.1 (GND), U2.5 (SDO), U2.7 (GND), U7.2 (GND); also elsewhere on the board
unnamed: C16.2, R26.1, R28.2
unnamed: C17.1, MK1.OUT, R28.1
unnamed: C19.1, R30.1
unnamed: R17.3, R31.2
unnamed: C17.2, R27.1, R29.2, U7.1 (IN+)
unnamed: C20.1, R30.2, R31.1, U7.3 (IN-)

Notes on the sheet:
PHOTO SENSOR
MICROPHONE AND AMPLIFER
(Q1)It has 3 pins in total we only connect 1 and 3.
Envinormental sensor

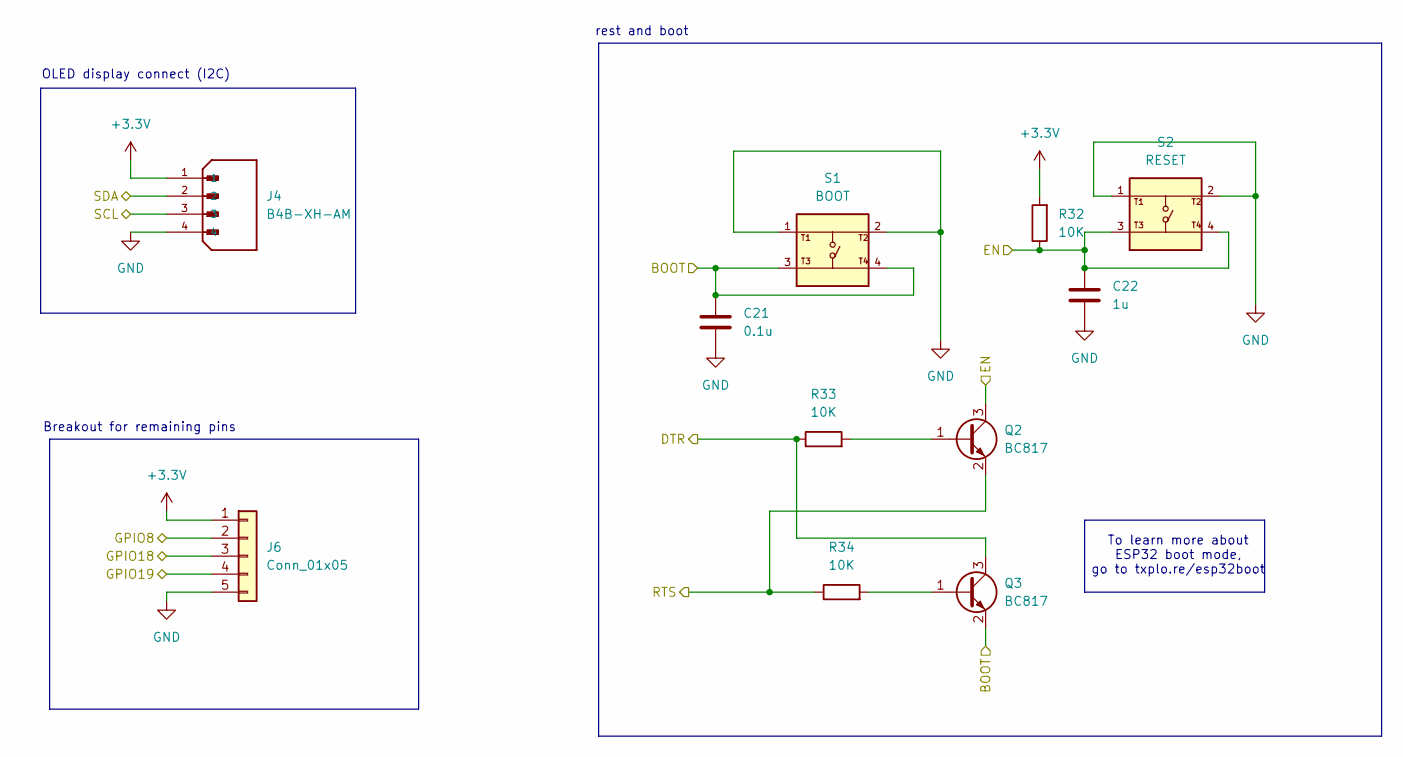
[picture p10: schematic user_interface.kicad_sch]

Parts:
C21: 0.1u; C_0805_2012Metric
C22: 1u; C_0805_2012Metric
J4: B4B-XH-AM; JST_B4B-XH-AM__LF__SN_; PARTREV N/A
J6: Conn_01x05; PinHeader_1x05_P2.54mm_Vertical
Q2, Q3: BC817; SOT-23
R32, R33, R34: 10K; R_0805_2012Metric
S1: BOOT; SW_USLPT2819DT2TR; PARTREV P
S2: RESET; SW_USLPT2819DT2TR; PARTREV P

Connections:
+3.3V: J4.1, J6.1, R32.2; also elsewhere on the board
/ESP32-c3-02/BOOT: C21.1, Q3.2 (E), S1.3, S1.4; also elsewhere on the board
/ESP32-c3-02/DTR: Q3.3 (C), R33.1; also elsewhere on the board
/ESP32-c3-02/EN: C22.1, Q2.3 (C), R32.1, S2.3, S2.4; also elsewhere on the board
/ESP32-c3-02/GPIO8: J6.2; also elsewhere on the board
/ESP32-c3-02/GPIO18: J6.3; also elsewhere on the board
/ESP32-c3-02/GPIO19: J6.4; also elsewhere on the board
/ESP32-c3-02/RTS: Q2.2 (E), R34.1; also elsewhere on the board
/ESP32-c3-02/SCL: J4.3; also elsewhere on the board
/ESP32-c3-02/SDA: J4.2; also elsewhere on the board
GND: C21.2, C22.2, J4.4, J6.5, S1.1, S1.2, S2.1, S2.2; also elsewhere on the board
unnamed: Q2.1 (B), R33.2
unnamed: Q3.1 (B), R34.2

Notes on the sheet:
OLED display connect (I2C)
rest and boot
Breakout for remaining pins
To learn more about ESP32 boot mode, go to txplo.re/esp32boot

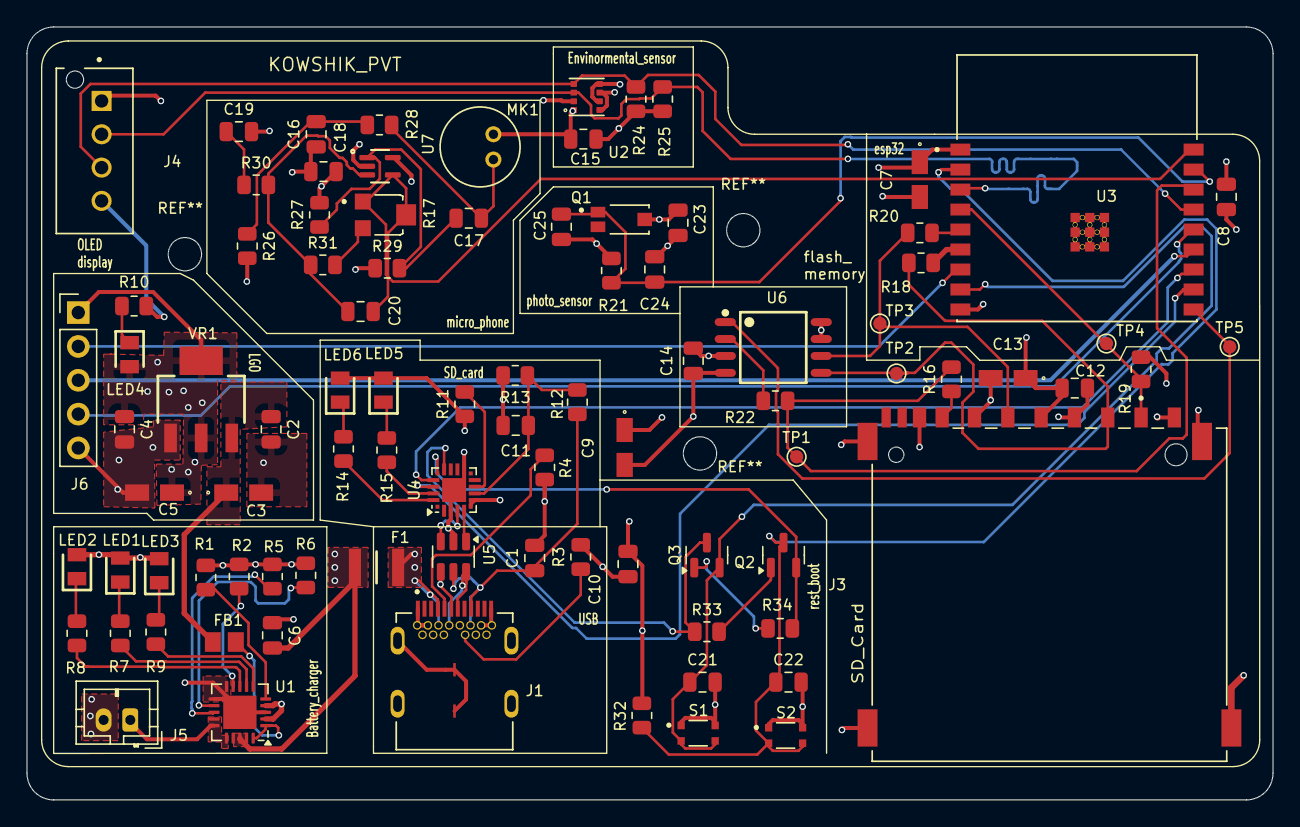
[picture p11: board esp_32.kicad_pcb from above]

Board: 4 copper layers, 93.5 x 58.0 mm, 90 parts (0 on the bottom side), 60 nets.
